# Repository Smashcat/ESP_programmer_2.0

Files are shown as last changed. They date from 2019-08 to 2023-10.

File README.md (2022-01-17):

# ESP_programmer_2.0
A USB to serial device plus circuit to automatically put ESP8266 and ESP32 modules into programming mode when programming via Arduino. Board is based around the CP2104 USB to serial bridge. All parts surface mount, except for header pins - project created using Eagle.

Photo of ESP programmer V2.0 board

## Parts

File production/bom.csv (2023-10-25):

Qty | Designator | Footprint | Comment | LCSC Part # | Description | Device
1 | C4 | C0603 | 0.1uF | C14663 | CAPACITOR, European symbol | C-EUC0603
1 | J1 | FCI_10118193-0001LF | 10118193-0001LF | C132562 | Micro USB B Type Receptacle | 10118193-0001LF
2 | R2, R3 | 603 | 10k | C25804 | 10kΩ resistor | 10KOHM-0603-1/10W-1%
2 | C1, C5 | C0603 | 10uF | C96446 | CAPACITOR, European symbol | C-EUC0603
5 | R1, R4, R5, R6, R11 | 603 | 1k | C21190 | 10kΩ resistor | 10KOHM-0603-1/10W-1%
5 | GPIO0_LED, PWR_LED, RESET_LED, RX_LED, TX_LED | CHIP-LED0603 | 20mA | C2290 | LED | LEDCHIP-LED0603
1 | REG | NCP718BSN330T1G | 3v3 LDO | C587158 |  | NCP718BSN330T1G
1 | U1 | QFN50P400X400X80-25N | CP2104-F03-GM | C47742 | Silabs CP2104 USB to UART Bridge | CP2104-F03-GM
2 | Q2, Q3 | ON_SEMICONDUCTOR_BC849BLT1G_0 | ON_SEMICONDUCTOR_BC849BLT1GON_SEMICONDUCTOR_BC849BLT1G_0_0 | C2146 | ONSC-NPN-B1E2C3-3 | ON_SEMICONDUCTOR_BC849BLT1GON_SEMICONDUCTOR_BC849BLT1G_0_0

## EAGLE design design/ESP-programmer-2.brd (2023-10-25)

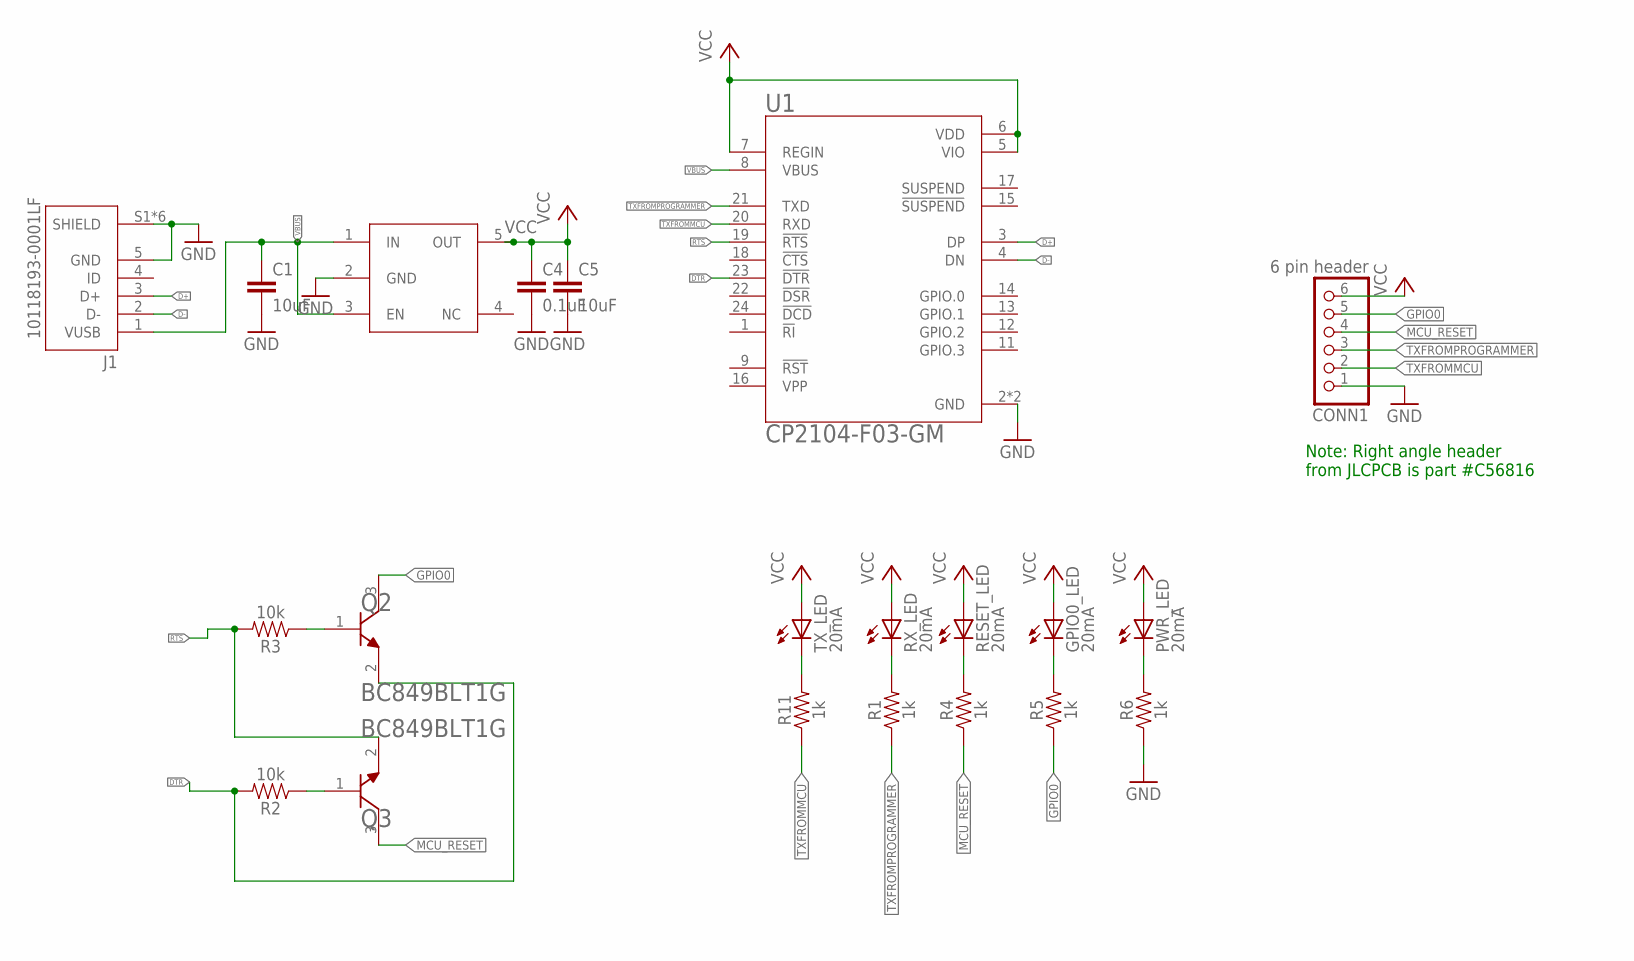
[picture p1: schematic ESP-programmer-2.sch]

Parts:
C1, C5: 10uF; C0603
C4: 0.1uF; C0603
CONN1: 6 pin header; 1X06
GPIO0_LED: 20mA; CHIP-LED0603
J1: 10118193-0001LF; FCI_10118193-0001LF
PWR_LED: 20mA; CHIP-LED0603
Q2, Q3: ON_SEMICONDUCTOR_BC849BLT1GON_SEMICONDUCTOR_BC849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; ON_SEMICONDUCTOR_BC849BLT1G_0
R1, R4, R5, R6, R11: 1k; 0603
R2, R3: 10k; 0603
REG: 3v3 LDO; NCP718BSN330T1G
RESET_LED: 20mA; CHIP-LED0603
RX_LED: 20mA; CHIP-LED0603
TX_LED: 20mA; CHIP-LED0603
U1: CP2104-F03-GM; QFN50P400X400X80-25N

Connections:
D+: J1.3 (D+), U1.3 (DP)
D-: J1.2 (D-), U1.4 (DN)
DTR: Q2.2 (E), R2.2, U1.23 (!DTR)
GND: C1.2, C4.2, C5.2, CONN1.1, J1.5 (GND), J1.S1 (SHIELD), J1.S2 (SHIELD), J1.S3 (SHIELD), J1.S4 (SHIELD), J1.S5 (SHIELD), J1.S6 (SHIELD), R6.1, REG.2 (GND), U1.2 (GND), U1.25 (GND)
GPIO0: CONN1.5, Q2.3 (C), R5.1
MCU_RESET: CONN1.4, Q3.3 (C), R4.1
unnamed: Q3.1 (B), R2.1
unnamed: Q2.1 (B), R3.1
RTS: Q3.2 (E), R3.2, U1.19 (!RTS)
STATUSTOLED: R11.2, TX_LED.C
STATUSTOLED1: R1.2, RX_LED.C
STATUSTOLED2: R4.2, RESET_LED.C
STATUSTOLED3: GPIO0_LED.C, R5.2
STATUSTOLED4: PWR_LED.C, R6.2
TXFROMMCU: CONN1.2, R11.1, U1.20 (RXD)
TXFROMPROGRAMMER: CONN1.3, R1.1, U1.21 (TXD)
VBUS: C1.1, J1.1 (VUSB), REG.1 (IN), REG.3 (EN), U1.8 (VBUS)
VCC: C4.1, C5.1, CONN1.6, GPIO0_LED.A, PWR_LED.A, REG.5 (OUT), RESET_LED.A, RX_LED.A, TX_LED.A, U1.5 (VIO), U1.6 (VDD), U1.7 (REGIN)

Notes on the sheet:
Note: Right angle header from JLCPCB is part #C56816

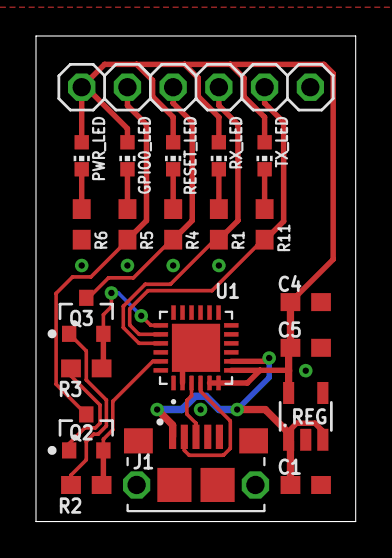
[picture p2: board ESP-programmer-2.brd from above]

Board: 2 copper layers, 17.8 x 27.0 mm, 21 parts (0 on the bottom side), 18 nets.

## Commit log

2022-01-17 Added production and assembly files
    [ESP-programmer-2.brd, ESP-programmer-2.sch, bom.csv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]
2023-10-25 Fixed errors in mount file
    [ESP-programmer-2.brd, ESP-programmer-2.sch, bom.csv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]

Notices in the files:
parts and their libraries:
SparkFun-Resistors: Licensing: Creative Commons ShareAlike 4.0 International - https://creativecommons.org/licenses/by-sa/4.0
